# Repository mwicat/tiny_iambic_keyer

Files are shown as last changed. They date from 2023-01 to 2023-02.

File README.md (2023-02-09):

# tiny_iambic_decoder implemented on ATTiny85

Allows to use iambic (dual lever) morse paddle with inputs that expect normal paddle.

## Background story

Some morse code enthusiast gave me a [pocket morse code reader device](https://www.hamradiostore.co.uk/product/mfj-461/) that can listen to morse code sound and then decode it and display as text on LCD screen. The problem is that he wants to use it with [dual lever paddle](https://www.onallbands.com/215/) also known as iambic keyer. The keyer won't generate a sound needed by morse reader and the extra difficulty is that dual lever paddle has two outputs - one for "dit" symbol and another one for "dah". The signals from the outputs have to be interpreted and then the relevant sound generated basing on that information (short duration sine wave for "dit" and the long sine for "dah"). 

## I/O

Input:
- Two LOW/HIGH signals (pin 3 and pin 4) from dual lever paddle connected through stereo mini jack 3.5mm socket. The paddle will short the either connection representing dit or dah to ground so the MCU can interpret the lever being pushed as LOW value on input pin.

Outputs:
- LOW/HIGH Signal on pin 2 to drive the relay. The purpose of the relay is to simulate what normal paddle does when it is connected to the transmitter - that is, to ground single signal line when morse operator pushes the lever and to open it when he/she lets the lever go.
- Audio signal generated with pulse width modulation so that you can just connect it to audio amplifier and listen to dits and dahs sounds without the transmitter.

## Connections

<figure>
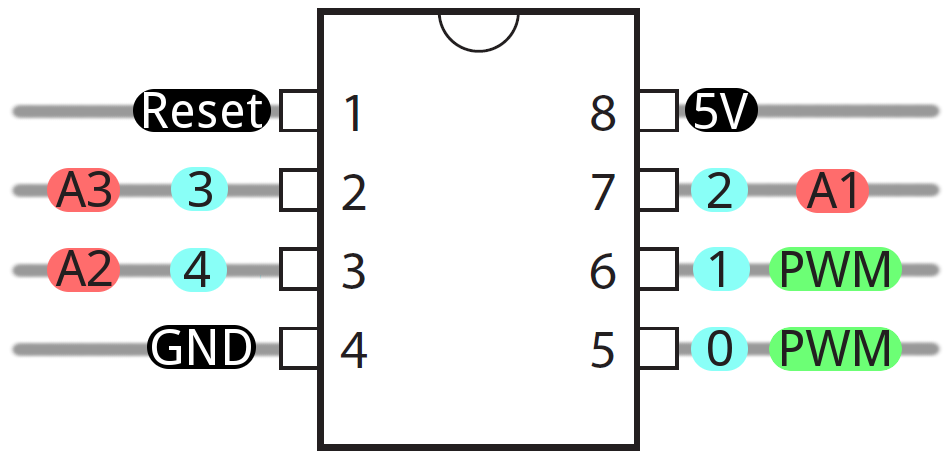
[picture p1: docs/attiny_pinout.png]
ATTiny85 pinout

<figcaption>ATTiny85 pinout</figcaption>
</figure>

<figure>
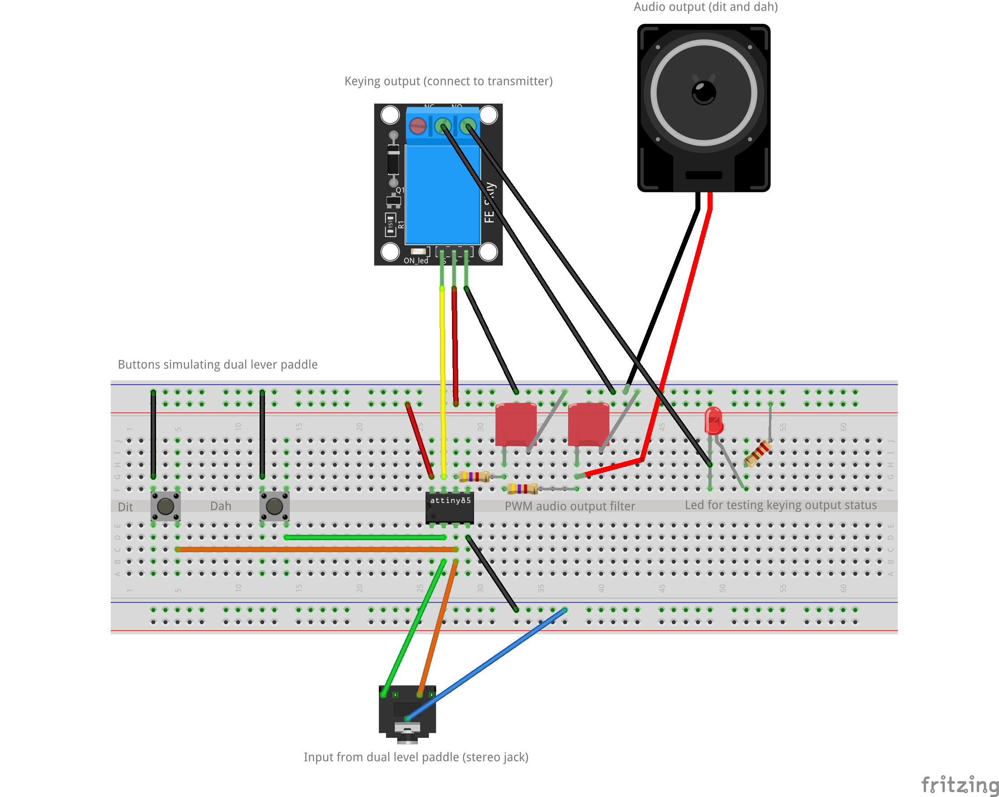
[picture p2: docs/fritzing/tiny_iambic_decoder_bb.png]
Tiny iambic decoder breadboard

<figcaption>Tiny iambic decoder breadboard</figcaption>
</figure>

<figure>
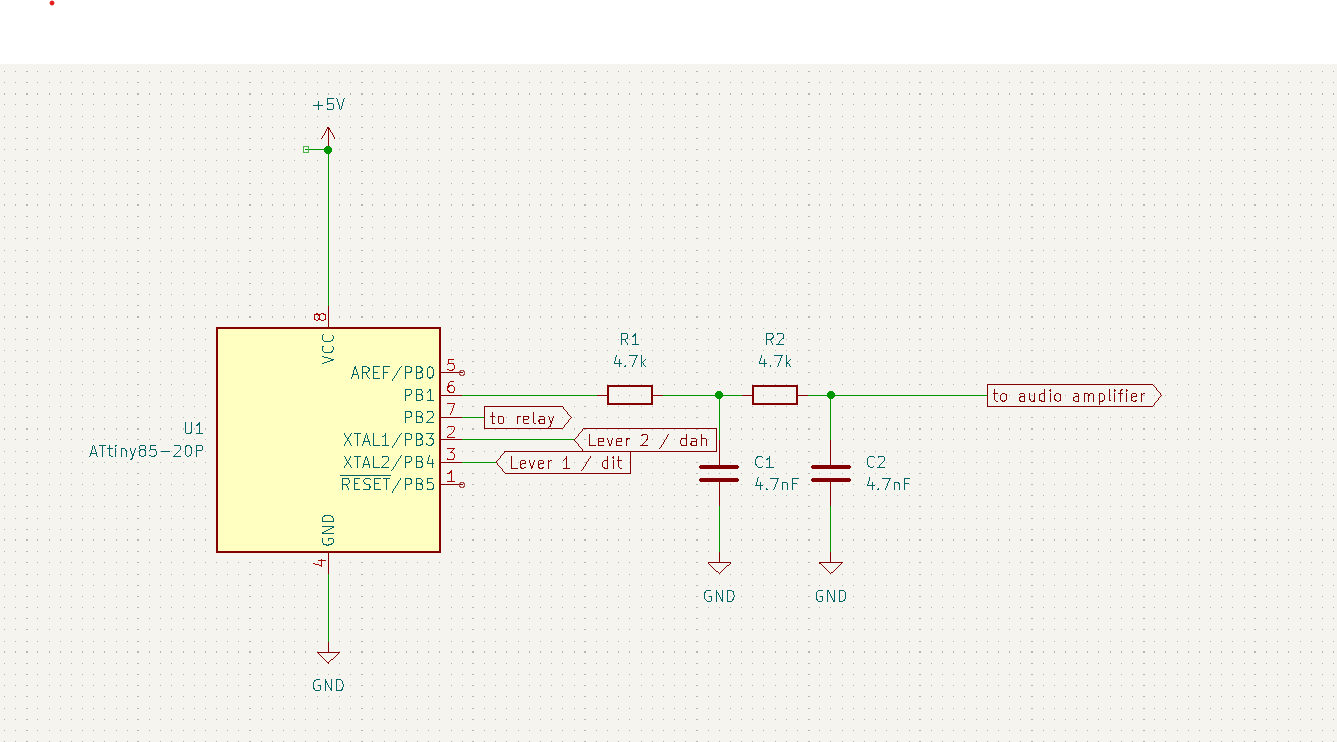
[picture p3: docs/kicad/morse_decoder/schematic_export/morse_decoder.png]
Tiny iambic decoder schematic

<figcaption>Tiny iambic decoder schematic</figcaption>
</figure>

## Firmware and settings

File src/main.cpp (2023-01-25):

#include <stdio.h>
#include <Arduino.h>

#include "morse_player.hpp"

#include "dds.hpp"


const int relay_out_pin = 2;

const int dot_in_pin = 3;
const int dash_in_pin = 4;

bool play_tone = false;
bool dot_btn_pushed = false;
bool dash_btn_pushed = false;
bool ready_to_switch = false;

Player* player;


void switchRelay(bool on) {
  digitalWrite(relay_out_pin, on ? LOW : HIGH);
}

void play_state_changed_cb(PlayState play_state) {
  switch (play_state) {
    case PLAY_STATE_DOT_ON:
    case PLAY_STATE_DASH_ON:
      play_tone = true;
      break;
    case PLAY_STATE_DOT_OFF:
    case PLAY_STATE_DASH_OFF:
    case PLAY_STATE_STOPPED:
    case PLAY_STATE_UNSET:
      play_tone = false;
      break;
  }
  switchRelay(play_tone);
}


void setup() {
  pinMode(relay_out_pin, OUTPUT);
  pinMode(dot_in_pin, INPUT_PULLUP);
  pinMode(dash_in_pin, INPUT_PULLUP);
  switchRelay(false);
  Freq = 700;
  CalculateSine();
  SetupDDS();
  Jump = Freq*4;
  player = new Player(100 * 30, &play_state_changed_cb, &millis);
}

ISR(TIMER0_COMPA_vect) {
  if (play_tone) {
    Sine();
  }
}

void loop() {
  if (ready_to_switch) {
    dot_btn_pushed = (digitalRead(dot_in_pin) == LOW);
    dash_btn_pushed = (digitalRead(dash_in_pin) == LOW);

    if (dot_btn_pushed) {
      player->playDot();
    } else if (dash_btn_pushed) {
      player->playDash();
    } else {
      player->stop();
    }
  }

  ready_to_switch = player->step();
}

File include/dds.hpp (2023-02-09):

#ifndef DDS_HPP
#define DDS_HPP

#include <Arduino.h>

#define NOINIT __attribute__ ((section (".noinit")))

unsigned int Freq NOINIT;
int8_t Sinewave[256] NOINIT;

volatile unsigned int Acc, Jump;


void CalculateSine () {
  int X=0, Y=8180;
  for (int i=0; i<256; i++) {
    X = X + (Y*4)/163;
    Y = Y - (X*4)/163;
    Sinewave[i] = X>>6;
  }
}

void Sine () {
  Acc = Acc + Jump;
  OCR1A = Sinewave[Acc>>8] + 128;
}

void SetupDDS () {
  // Enable 64 MHz PLL and use as source for Timer1
  PLLCSR = 1<<PCKE | 1<<PLLE;

  // Set up Timer/Counter1 for PWM output
  TIMSK = 0;                               // Timer interrupts OFF
  TCCR1 = 1<<PWM1A | 2<<COM1A0 | 1<<CS10;  // PWM A, clear on match, 1:1 prescale
  pinMode(1, OUTPUT);                      // Enable PWM output pin

  // Set up Timer/Counter0 for 20kHz interrupt to output samples.
  TCCR0A = 3<<WGM00;                       // Fast PWM
  TCCR0B = 1<<WGM02 | 2<<CS00;             // 1/8 prescale (1MHz)
  //TIMSK = 1<<OCIE0A;                     // Enable compare match, disable overflow
  TIMSK = 1<<OCIE0A | 1<<TOIE0;            // Enable compare match, disable overflow

  //   The Output Compare Register A contains an 8-bit value that is continuously compared with the counter value
  // (TCNT0). A match can be used to generate an Output Compare interrupt, or to generate a waveform output on the
  // OC0A pin.
  OCR0A = 60;                              // Divide by 61 - Timer/Counter0 – Output Compare Register A
}
#endif

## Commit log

2023-02-09 Add docs
    [tiny_iambic_decoder_bb.fzz]
2023-02-09 update docs
    [tiny_iambic_decoder_bb.fzz]
2023-02-09 Update schematics
    [tiny_iambic_decoder_bb.fzz]
2023-02-09 Add kicad files
    [morse_decoder.kicad_pcb, morse_decoder.kicad_sch]
2023-02-09 Replace svg schematic with png one
